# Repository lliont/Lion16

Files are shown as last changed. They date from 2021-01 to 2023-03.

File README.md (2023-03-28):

# Lion
Lion FPGA CPU/Computer

The Lion computer project files.

Lion CPU is a homebrew CPU and Lion Computer is a homebrew 16-bit computer based on this cpu.

lionsys.sof and lionsys.jic are the files for configuration of a QMTech Cyclone V FPGA board for Lion.

sdcard.zip contains files for the 30MB FAT partition on a SDCard for Lion to boot.

Lionasm.exe is an assembler for Lion.

Liontiny.asm is the Basic source file that when compiled and it's output Liontiny.bin is named BOOT.BIN (exists in sdcard.zip) and copied to sdcard it boots lion in tiny basic.

Lion1.sch and Lion1.brd are eagle files for the Lion base board.

Hardware design and software released under the Creative Commons License BY-NC-SA https://creativecommons.org/licenses/by-nc-sa/4.0/

Theodoulos Liontakis

Project Pages:

http://users.sch.gr/tliontakis/index.php/my-projects/13-vhdl-cpu

https://hackaday.io/project/162876-lion-fpga-cpucomputer

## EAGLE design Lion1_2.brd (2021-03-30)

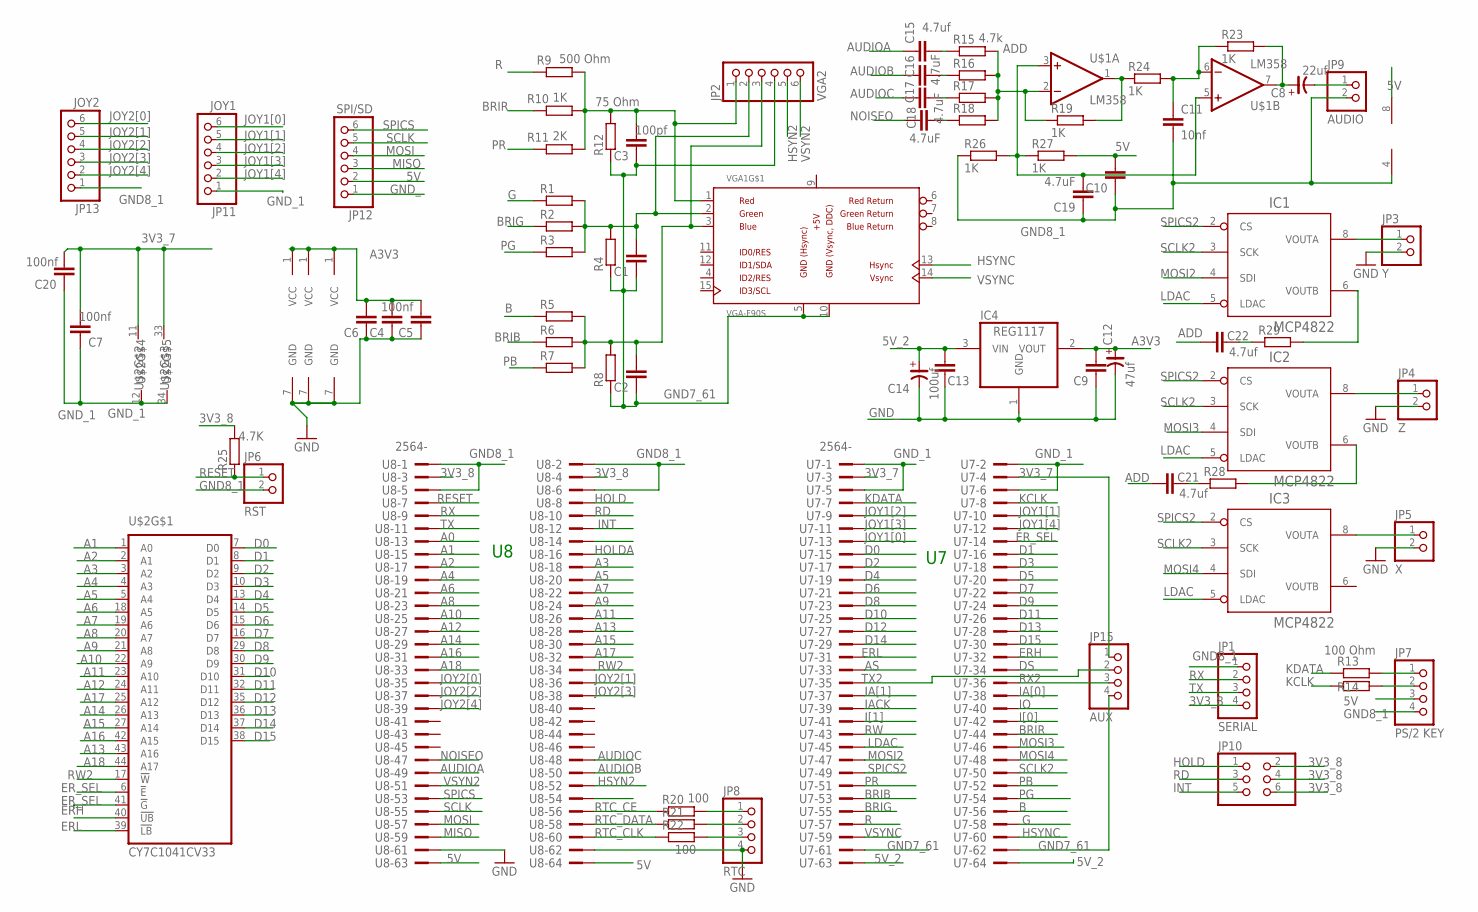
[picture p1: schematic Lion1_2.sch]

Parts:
C1, C2, C4, C6, C9, C10, C13: C-EU050-025X075; C050-025X075
C3: 100pf; C050-025X075
C5: 100nf; C050-025X075
C7, C20: 100nf; C0805
C8: 22uf; CE-025X060
C11: 10nf; C050-025X075
C12: 47uf; CE-025X060
C14: 100uf; CE-025X060
C15, C21, C22: 4.7uf; C050-025X075
C16, C17, C18, C19: 4.7uF; C050-025X075
IC1, IC2, IC3: MCP4822; DIL08
IC4: REG1117; SOT223
JP1: SERIAL; 1X04
JP2: VGA2; 1X06
JP3: Y; 1X02
JP4: Z; 1X02
JP5: X; 1X02
JP6: RST; 1X02
JP7: PS/2 KEY; 1X04
JP8: RTC; 1X04
JP9: AUDIO; 1X02
JP10: PINHD-2X3; 2X03
JP11: JOY1; 1X06
JP12: SPI/SD; 1X06
JP13: JOY2; 1X06
JP15: AUX; 1X04
R1, R2, R3, R4, R5, R6, R7, R8, R14, R22: R-EU_0204/7; 0204/7
R9: 500 Ohm; 0204/7
R10, R19, R23, R24, R26, R27: 1K; 0204/7
R11: 2K; 0204/7
R12: 75 Ohm; 0204/7
R13: 100 Ohm; 0204/7
R15: 4.7k; 0204V
R16, R17, R18, R28, R29: R-EU_0204/2V; 0204V
R20, R21: 100; 0204/7
R25: 4.7K; 0204/5
U7, U8: 2564-; PAK100/2500-64
U$1: LM358; DIL8
U$2: CY7C1041CV33; TSOP44-II
VGA1: VGA-F90S; DB-15-F90+SHIELD-SMALL_PADS

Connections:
3V3_7: C7.2, C20.2, JP15.1, U7.3, U7.4, U$2.11 (VCC), U$2.33 (VCC)
3V3_8: JP1.4, JP10.2, JP10.4, JP10.6, R25.2, U8.3, U8.4
5V: C10.2, JP7.3, JP12.2, R27.2, U8.63, U8.64, U$1.8 (V+)
5V_2: C13.2, C14.+, IC4.3 (VIN), U7.63, U7.64
+5V: VGA1.9 (+5V)
A0: U8.13
A1: U8.15, U$2.1 (A0)
A2: U8.17, U$2.2 (A1)
A3: U8.18, U$2.3 (A2)
A3V3: C4.2, C5.2, C6.2, C9.2, C12.+, IC1.1 (VCC), IC2.1 (VCC), IC3.1 (VCC), IC4.2 (VOUT)
A4: U8.19, U$2.4 (A3)
A5: U8.20, U$2.5 (A4)
A6: U8.21, U$2.18 (A5)
A7: U8.22, U$2.19 (A6)
A8: U8.23, U$2.20 (A7)
A9: U8.24, U$2.21 (A8)
A10: U8.25, U$2.22 (A9)
A11: U8.26, U$2.23 (A10)
A12: U8.27, U$2.24 (A11)
A13: U8.28, U$2.43 (A16)
A14: U8.29, U$2.26 (A13)
A15: U8.30, U$2.27 (A14)
A16: U8.31, U$2.42 (A15)
A17: U8.32, U$2.25 (A12)
A18: U8.33, U$2.44 (A17)
ADD: C21.1, C22.1, R15.2, R16.2, R17.2, R18.2, R19.1, U$1.2 (-IN)
AS: U7.33
AUDIOA: C15.1, U8.49
AUDIOB: C16.1, U8.50
AUDIOC: C17.1, U8.48
B: R5.1, U7.56
BRIB: R6.1, U7.53
BRIG: R2.1, U7.55
BRIR: R10.1, U7.44
D0: U7.15, U$2.7 (D0)
D1: U7.16, U$2.8 (D1)
D2: U7.17, U$2.9 (D2)
D3: U7.18, U$2.10 (D3)
D4: U7.19, U$2.13 (D4)
D5: U7.20, U$2.14 (D5)
D6: U7.21, U$2.15 (D6)
D7: U7.22, U$2.16 (D7)
D8: U7.23, U$2.29 (D8)
D9: U7.24, U$2.30 (D9)
D10: U7.25, U$2.31 (D10)
D11: U7.26, U$2.32 (D11)
D12: U7.27, U$2.35 (D12)
D13: U7.28, U$2.36 (D13)
D14: U7.29, U$2.37 (D14)
D15: U7.30, U$2.38 (D15)
DS: U7.34
ERH: U7.32, U$2.40 (!UB)
ERL: U7.31, U$2.39 (!LB)
ER_SEL: U7.14, U$2.6 (!E), U$2.41 (!G)
G: R1.1, U7.58
GND7_61: C1.1, C2.1, C3.1, JP2.4, JP15.4, R4.1, R8.1, R12.1, U7.61, U7.62, VGA1.5 (GND), VGA1.10 (GND)
GND8_1: C10.1, C11.2, C19.1, JP1.1, JP6.2, JP7.4, JP9.2, JP13.1, R26.1, U8.1, U8.2, U8.5, U8.6, U$1.4 (V-)
GND_: C4.1, C5.1, C6.1, C9.1, C12.-, C13.1, C14.-, IC1.7 (GND), IC2.7 (GND), IC3.7 (GND), IC4.1 (GND), JP3.2, JP4.2, JP5.2, JP8.4, JP12.1, U8.61, U8.62
GND_1: C7.1, C20.1, JP11.1, U7.1, U7.2, U7.5, U7.6, U$2.12 (VSS), U$2.34 (VSS)
HOLD: JP10.1, U8.8
HOLDA: U8.16
HSYN2: JP2.5, U8.52
HSYNC: U7.60, VGA1.13 (VGA-HSYNC)
IACK: U7.39
IA[0]: U7.38
IA[1]: U7.37
INT: JP10.5, U8.12
IO: U7.40
I[0]: U7.42
I[1]: U7.41
JOY1[0]: JP11.6, U7.13
JOY1[1]: JP11.5, U7.10
JOY1[2]: JP11.4, U7.9
JOY1[3]: JP11.3, U7.11
JOY1[4]: JP11.2, U7.12
JOY2[0]: JP13.6, U8.35
JOY2[1]: JP13.5, U8.36
JOY2[2]: JP13.4, U8.37
JOY2[3]: JP13.3, U8.38
JOY2[4]: JP13.2, U8.39
KCLK: R14.1, U7.8
KDATA: R13.1, U7.7
LDAC: IC1.5 (LDAC), IC2.5 (LDAC), IC3.5 (LDAC), U7.45
MISO: JP12.3, U8.59
MOSI: JP12.4, U8.57
MOSI2: IC1.4 (SDI), U7.47
MOSI3: IC2.4 (SDI), U7.46
MOSI4: IC3.4 (SDI), U7.48
unnamed: C1.2, JP2.2, R1.2, R2.2, R3.2, R4.2, VGA1.2 (VGA-G)
unnamed: IC2.6 (VOUTB), R28.2
unnamed: C19.2, R26.2, R27.1, U$1.3 (+IN), U$1.5 (+IN)
unnamed: C15.2, R15.1
unnamed: IC3.8 (VOUTA), JP5.1
unnamed: C2.2, JP2.3, R5.2, R6.2, R7.2, R8.2, VGA1.3 (VGA-B)
unnamed: IC2.8 (VOUTA), JP4.1
unnamed: IC1.8 (VOUTA), JP3.1
unnamed: C21.2, R28.1
unnamed: C3.2, JP2.1, R9.2, R10.2, R11.2, R12.2, VGA1.1 (VGA-R)
unnamed: R19.2, R24.1, U$1.1 (OUT)
unnamed: JP7.1, R13.2
unnamed: JP7.2, R14.2
unnamed: C8.-, JP9.1
unnamed: JP8.1, R20.2
unnamed: JP8.2, R21.2
unnamed: JP8.3, R22.2
unnamed: C8.+, R23.2, U$1.7 (OUT)
unnamed: C11.1, R23.1, R24.2, U$1.6 (-IN)
unnamed: C16.2, R16.1
unnamed: C17.2, R17.1
unnamed: C18.2, R18.1
unnamed: C22.2, R29.1
unnamed: IC1.6 (VOUTB), R29.2
NOISEO: C18.1, U8.47
PB: R7.1, U7.52
PG: R3.1, U7.54
PR: R11.1, U7.51
R: R9.1, U7.57
RD: JP10.3, U8.10
RESET: JP6.1, R25.1, U8.7
RTC_CE: R20.1, U8.56
RTC_CLK: R22.1, U8.60
RTC_DATA: R21.1, U8.58
RW: U7.43
RW2: U8.34, U$2.17 (!W)
RX: JP1.2, U8.9
RX2: JP15.3, U7.36
SCLK: JP12.5, U8.55
SCLK2: IC1.3 (SCK), IC2.3 (SCK), IC3.3 (SCK), U7.50
SPICS: JP12.6, U8.53
SPICS2: IC1.2 (CS), IC2.2 (CS), IC3.2 (CS), U7.49
TX: JP1.3, U8.11
TX2: JP15.2, U7.35
VSYN2: JP2.6, U8.51
VSYNC: U7.59, VGA1.14 (VGA-VSYNC)

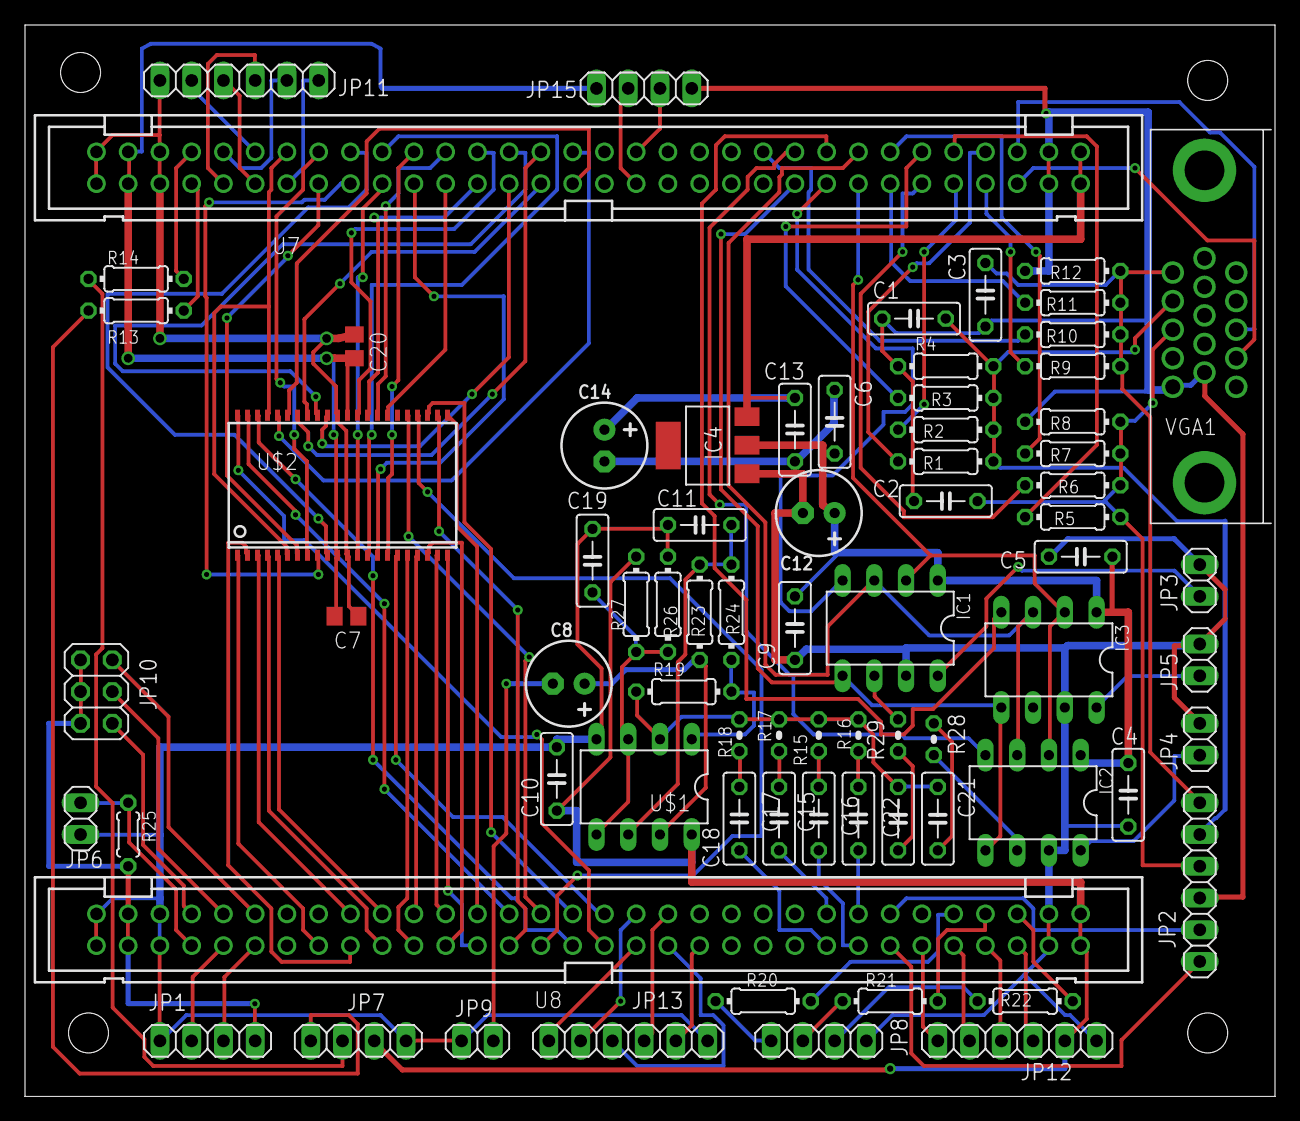
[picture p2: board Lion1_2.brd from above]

Board: 2 copper layers, 100.0 x 85.7 mm, 74 parts (0 on the bottom side), 122 nets.

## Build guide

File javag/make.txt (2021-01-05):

To make the astro4.bin (or any other bin from an asm file) you needed to run Astro in Lion  :

javac astro4S.class
java_grinder astro4S.class astro4S.asm Lionsys
jgoptimizer astro4S.asm astro4.asm

Then open astro4.asm with lionasm and compile 

The code produced is relalocatable and can be loaded and run from anyware in memory range btop (about 17000) to 48000-bin_file_size.
The function btop always returns the first free andress after the basic program area.

A convinient way to load a binary and execute it is:

LCODE "astro4",btop
RCODE btop

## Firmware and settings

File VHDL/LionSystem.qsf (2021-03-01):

# -------------------------------------------------------------------------- #
#
# Copyright (C) 1991-2012 Altera Corporation
# Your use of Altera Corporation's design tools, logic functions 
# and other software and tools, and its AMPP partner logic 
# functions, and any output files from any of the foregoing 
# (including device programming or simulation files), and any 
# associated documentation or information are expressly subject 
# to the terms and conditions of the Altera Program License 
# Subscription Agreement, Altera MegaCore Function License 
# Agreement, or other applicable license agreement, including, 
# without limitation, that your use is for the sole purpose of 
# programming logic devices manufactured by Altera and sold by 
# Altera or its authorized distributors.  Please refer to the 
# applicable agreement for further details.
#
# -------------------------------------------------------------------------- #
#
# Quartus II 32-bit
# Version 12.1 Build 243 01/31/2013 Service Pack 1.33 SJ Web Edition
# Date created = 11:10:35  June 14, 2015
#
# -------------------------------------------------------------------------- #
#
# Notes:
#
# 1) The default values for assignments are stored in the file:
#		LionSystem_assignment_defaults.qdf
#    If this file doesn't exist, see file:
#		assignment_defaults.qdf
#
# 2) Altera recommends that you do not modify this file. This
#    file is updated automatically by the Quartus II software
#    and any changes you make may be lost or overwritten.
#
# -------------------------------------------------------------------------- #



# Project-Wide Assignments
# ========================
set_global_assignment -name ORIGINAL_QUARTUS_VERSION "12.1 SP1"
set_global_assignment -name PROJECT_CREATION_TIME_DATE "16:50:00  MAY 06, 2015"
set_global_assignment -name LAST_QUARTUS_VERSION "18.1.1 Lite Edition"
set_global_assignment -name PROJECT_OUTPUT_DIRECTORY output_files
set_global_assignment -name SMART_RECOMPILE OFF

# Pin & Location Assignments
# ==========================

# Classic Timing Assignments
# ==========================
set_global_assignment -name MIN_CORE_JUNCTION_TEMP "-40"
set_global_assignment -name MAX_CORE_JUNCTION_TEMP 100
set_global_assignment -name TIMING_ANALYZER_MULTICORNER_ANALYSIS OFF

# Analysis & Synthesis Assignments
# ================================
set_global_assignment -name FAMILY "Cyclone V"
set_global_assignment -name TOP_LEVEL_ENTITY LionSystem
set_global_assignment -name VHDL_INPUT_VERSION VHDL_2008
set_global_assignment -name VHDL_SHOW_LMF_MAPPING_MESSAGES OFF

# Fitter Assignments
# ==================
set_global_assignment -name DEVICE 5CEFA2F23I7
set_global_assignment -name ERROR_CHECK_FREQUENCY_DIVISOR 1
set_global_assignment -name STRATIX_DEVICE_IO_STANDARD "3.3-V LVTTL"

# EDA Netlist Writer Assignments
# ==============================
set_global_assignment -name EDA_SIMULATION_TOOL "<None>"

# Power Estimation Assignments
# ============================
set_global_assignment -name POWER_PRESET_COOLING_SOLUTION "23 MM HEAT SINK WITH 200 LFPM AIRFLOW"
set_global_assignment -name POWER_BOARD_THERMAL_MODEL "NONE (CONSERVATIVE)"

# start EDA_TOOL_SETTINGS(eda_simulation)
# ---------------------------------------

	# EDA Netlist Writer Assignments
	# ==============================
set_global_assignment -name EDA_OUTPUT_DATA_FORMAT NONE -section_id eda_simulation

# end EDA_TOOL_SETTINGS(eda_simulation)
# -------------------------------------

# ------------------------
# start ENTITY(LionSystem)

	# start DESIGN_PARTITION(Top)
	# ---------------------------

		# Incremental Compilation Assignments
		# ===================================

	# end DESIGN_PARTITION(Top)
	# -------------------------
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

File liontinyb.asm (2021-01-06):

;*       Tiny Basic port for Lion cpu/System
;*
;*         ported by Theodoulos Liontakis 2016
;*
;*          from  michael sullivan's 8086 port of
;*                               
;*                   Li-Chen Wang's
;*
;*                   8080 tiny basic 
;*
;* (c)copyleft
;* all wrongs reserved
;*
;*  New commands and fixed point arithmetic added


SDCBUF1	EQU	$2000  ;DS	514  Buffer 1 
SDCBUF2	EQU	$2202  ;DS	514  Buffer 2
FATBOOT	EQU	$2404  ;DS	2    Fat boot #sector 
DIRROOT	EQU	$2406  ;DS	2    Root directory #sector 
FSTCLST	EQU	$2408  ;DS	2    First data #sector
FSTFAT	EQU	$240a  ;DS	2    First Fat first #sector
SDFLAG	EQU	$240c  ;DS	2    SD card initialized by rom=256
COUNTER     EQU	$240e  ;DS	2    General use counter increased by int 3 
FRAC1		EQU	$2410  ;DS	2    for fixed point multiplication-division
FRAC2		EQU  	$2412  ;DS	2               >>
RHINT0	EQU	$2414  ; Hardware interrupt 0
RHINT1	EQU	$2418  ; Hardware interrupt 1
RHINT2	EQU	$241c
RINT6		EQU	$2420
RINT7		EQU	$2424
RINT8		EQU	$2428
RINT9		EQU	$242c
RINT15	EQU	$2430
XCN         EQU   79
YCN         EQU   29
VMODE		EQU   $2434
SCOL		EQU   $2435
SHIFT       EQU	$2436
CAPSL       EQU	$2437
CIRCX		EQU	$2438
CIRCY		EQU	$243A
PLOTM		EQU	$243C
SECNUM      EQU   $243E
SECPFAT     EQU   $2440
FATROOT     EQU   $2442
RESRVB      EQU	$244E

ORG     	$2448  ;Ram

; RAM program ENTRY POINT
; A7 Reserved for decimal (was num2), in A6 fraction result of TSTNUM

START:	CLI
		MOV	A1,STACK 
		SETSP	A1
		STI
		JSR	CLRMEM
		IN	A1,24  ; get mode
		CMPI  A1,1
		JZ	VM1
		MOV	(DEFY),29
		MOV	(DEFX),79
		MOV.B   (PLOTM),1
		SETX  1589     ; set colors 
		MOV	A1,61152 
COLINIT:	OUT	A1,$F1F1
		JXAW	A1,COLINIT
		JR	12
VM1:		MOV	(DEFY),24
		MOV   (DEFX),52
		SETX	15   ; disable sprites mode 1
		MOV	A3,16391
		MOV	A4,16391+256
SPRLP1:	OUT.B A3,0
		OUT.B	A4,0
		ADD	A3,4096
		ADD	A4,4096
		OUT.B A3,0
		OUT.B	A4,0
		ADD	A3,4096
		ADD	A4,4096
		OUT.B A3,0
		OUT.B	A4,0
		SUB	A3,8184
		SUB   A4,8184
		JMPX	SPRLP1
		MOV	A1,$1F
		MOV.B	(SCOL),A1
		MOV	A3,(DEFY)
		MOV	(XX),A3     ;$001D ; Set INITIAL POS 
		MOV	A3,TITLE
		MOVI	A2,0
		MOVI	A0,0
		JSR	PRTSTG
		MOV	A3,TXTBGN
		MOV	A4,A3
		MOV	(TXTUNF),A3

RSTART:	CLI
		MOVI  A7,0
 		MOVI  A6,0
		MOV	A0,STACK
		SETSP	A0
		STI
		IN	A1,24
		MOV	(DEFY),29
		MOV	(DEFX),79
		CMPI	A1,1
		JNZ   ST2
		MOV	(DEFX),52
		MOV	(DEFY),24
ST2:		MOVI	A1,0
		MOV	(LOPVAR),A1
		MOV	(STKGOS),A1
		MOV	(CURRNT),A1
		;JSR	CRLF
		MOV	A5,(DEFY)
		MOV	(XX),A5
		MOV   A3,OK 
		MOVI	A0,0
		JSR	prtstg
ST3:		MOV   (UINT),0
		MOVHL	A0,0
		MOV.B	A0,'>'
		JSR	GETLN
		PUSH	A4         ; A4 end of text in buffer
		MOV 	A3,BUFFER
		JSR	TSTNUM
		MOVHL	A0,0
		JSR	IGNBLNK
		OR	A1,A1      ; A1 num 
		POP	A2
		JZ	DIRECT
		SUBI	A3,2
		MOV	A0,A1
		MOV	A4,A3
		JSR	STOSW  ; store lineno to 
		PUSH	A2
		PUSH  A3
		MOV	A0,A2
		SUB	A0,A3
		PUSH	A0
		JSR	FNDLN
		PUSH	A3
		JNZ	ST4
		PUSH	A3
		JSR	FNDNXT

		POP	A2
		MOV	A1,(TXTUNF)
		JSR	MVUP
		MOV	A1,A2
		MOV	(TXTUNF),A1
ST4:		
		POP	A2
		MOV	A1,(TXTUNF)

		POP	A0
		PUSH	A1
		CMPI.B A0,3
		JZ	RSTART
		ADD	A0,A1
		MOV	A1,A0	
		MOV	A3,TXTEND
		CMP	A1,A3
		JNC	QSORRY
		MOV	(TXTUNF),A1
		POP	A3
		JSR	MVDOWN
		POP	A3
		POP	A1
		JSR	MVUP
		JMP	ST3

TSTV:		
		MOVHL	A0,'@'
		JSR	IGNBLNK
		JC	RET2
		JNZ	TV1
		JSR	PARN
		SLL	A1,2
		PUSH	A3
		XCHG	A1,A3
		JSR	SIZE
		CMP	A1,A3
		JC	ASORRY
		MOV 	A1,TXTEND
		SUB	A1,A3
		POP	A3
		RET

TV1:		CMP.B	A0,122 ;'z'  ; TEST VARIABLE
		JA	RET22
		CMP.B	A0,97
            JAE   TV2
		CMP.B A0,'Z'
		JA    RET22
		CMP.B A0,'A'
		JC	RET2
TV2:		INC	A3
		MOV	A1,VARBGN
		SUB.B	A0,65
		AND	A0,$00FF
		SLL	A0,2
		ADD	A1,A0
RET2:		
		RET	
RET22:	
		CMP.B	A0,255
		RET

;----- TSTNUM

TSTNUM:
		MOVI	A1,0
		MOV	A6,0
		MOVHL	A2,A1
		MOVHL	A0,0
		JSR	IGNBLNK
TN1:
		CMP.B	A0,'.'
		JZ	DECIM
		CMP.B	A0,'0'
		JC	RET2
		CMP.B A0,':'
		JNC	RET2
		ADD	A2,$0100
		PUSH	A2
		MOVI	A2,10
		MULU	A1,A2
		MOVI	A0,0
            MOV.B	A0,(A3)
		SUB.B	A0,'0'
		MOVHL	A0,0
		INC	A3
		ADD	A1,A0
		POP	A2
		MOV.B A0,(A3)
		JP	TN1

NFR:		PUSH	A3
		MOV	A3,NFND
		JMP	ERROR
QHOW:
		PUSH	A3
AHOW:	
		MOV	A3,HOW
		JMP	ERROR

DECIM:	PUSH	A1
		PUSH	A2
		PUSH	A4
		MOVI	A4,1
		MOVI	A1,0
		MOVI	A0,0
TN2:		INC	A3
		MOV.B	A0,(A3)
		CMP.B	A0,'0'
		JC	DRET
		CMP.B A0,':'
		JNC	DRET
		MOVI	A2,10
		MULU	A1,A2
		SUB.B	A0,'0'
		CMP	A4,10000
		JZ	QHOW
		MOVI	A2,10
		MULU	A4,A2
		ADD	A1,A0
		JNC	TN2	
		JMP	QHOW
DRET:		MOVI	A2,0
		MOV	A0,15
DTOB2:	OR	A0,A0
		JN	DTOBEND
		SLL	A1,1		
		CMP	A1,A4
		JC	DTOB1
		BSET	A2,A0
		DEC	A0
		SUB	A1,A4
		JNZ	DTOB2
		JMP	DTOBEND
DTOB1:	DEC	A0
		JMP	DTOB2	
DTOBEND:	MOV	A6,A2
		POP	A4
		POP	A2
		POP	A1
		RET

TSTUNUM:
		MOVI	A1,0
		MOV	A6,0
		MOVHL	A2,A1
		MOVHL	A0,0
		JSR	IGNBLNK
UTN1:
		CMP.B	A0,'0'
		JC	RET2
		CMP.B A0,':'  ; is digit ?
		JNC	RET2
		ADD	A2,$0100
		PUSH	A2
		MOVI	A2,10
		MULU	A1,A2
		;CMPI	A2,0
		JANZ	A2,QHOW
		MOVI	A0,0
            MOV.B	A0,(A3)
		SUB.B	A0,'0'
		MOVHL	A0,0
		INC	A3
		POP	A2
		ADD	A1,A0
		MOV.B A0,(A3)
		JNC	UTN1
		JMP   QHOW

;--------  tables ----
tab1:	
	TEXT	"LIS"
	DB	'T'+128
	DA	LIST
	TEXT	"NE"
	DB	'W'+128
	DA	NEW
	TEXT	"RU"
	DB	'N'+128
	DA	RUN
	TEXT	"BY"
	DB	'E'+128
	DA	NEW
	TEXT	"SLIS"
	DB	'T'+128
	DA	SLIST
	TEXT  "LOA"
	DB	'D'+128
	DA	LOAD
	TEXT  "SAV"
	DB	'E'+128
	DA	SAVE
	TEXT "FIN"
	DB	'D'+128
	DA	FIND
	TEXT	"DI"
	DB	'R'+128
	DA	DIR
	TEXT	"C"
	DB	'D'+128
	DA	CD


TAB2	TEXT	"PRIN"
	DB	'T'+128
	DA	PRINT
	TEXT	"I"
	DB	'F'+128
	DA	IFF
	TEXT	"NEX"
	DB	'T'+128
	DA	NEXT
	TEXT	"GOT"
	DB	'O'+128
	DA	GOTO
	TEXT	"GOSU"
	DB	'B'+128
	DA	GOSUB
	TEXT	"RETUR"
	DB	'N'+128
	DA	RETURN
	TEXT	"FO"
	DB	'R'+128
	DA	FOR
      TEXT	"PLO"
	DB	'T'+128
	DA	TPLOT
	TEXT	"PO"
	DB	'S'+128
      DA	ATCMD
	TEXT	"OUT"
	DB	'B'+128
	DA	OUTBCMD
	TEXT	"OU"
	DB	'T'+128
	DA	OUTCMD
	TEXT	"RE"
	DB	'M'+128
	DA	REM
	TEXT	"INPU"
	DB	'T'+128
	DA	INPUT
	DB	'?'+128
	DA	PRINT
	TEXT	"POK"
	DB	'E'+128
	DA	POKE
	TEXT	"COLO"
	DB	'R'+128
	DA	COLOR
	TEXT	"BEE"
	DB	'P'+128
	DA	BEEP
	TEXT  "LIN"
	DB    'E'+128
	DA	LINE
	TEXT  "CIRCL"
	DB    'E'+128
	DA	CIRCLE
	TEXT	"FCOLO"
	DB	'R'+128
	DA	FORE
	TEXT	"BCOLO"
	DB	'R'+128
	DA	BACK
	TEXT	"CLS"
	DB	'P'+128
	DA	CLSSP
	TEXT	"CL"
	DB	'S'+128
	DA	CLS
	TEXT	"LE"
	DB	'T'+128
	DA	LET
	TEXT	"SCREE"
	DB	'N'+128
	DA	SCREEN
	TEXT  "LCOD"
	DB	'E'+128
	DA	LCODE
	TEXT  "SCOD"
	DB	'E'+128
	DA	SCODE
	TEXT  "RCOD"
	DB	'E'+128
	DA	RCODE
	TEXT  "LSCR"
	DB	'N'+128
	DA	LSCRN
	TEXT  "GCOD"
	DB	'E'+128
	DA	GCODE
	TEXT  "DELET"
	DB	'E'+128
	DA	DELETE
	TEXT  "MOD"
	DB	'E'+128
	DA	MODE
	TEXT	"PMOD"
	DB	'E'+128
	DA	PLOTMD
	TEXT	"STO"
	DB	'P'+128
	DA	STOP
	DB 	128
	DA	DEFLT
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

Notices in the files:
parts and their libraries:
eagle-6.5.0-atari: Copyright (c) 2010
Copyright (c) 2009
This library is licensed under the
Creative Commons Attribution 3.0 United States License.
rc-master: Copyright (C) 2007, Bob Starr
